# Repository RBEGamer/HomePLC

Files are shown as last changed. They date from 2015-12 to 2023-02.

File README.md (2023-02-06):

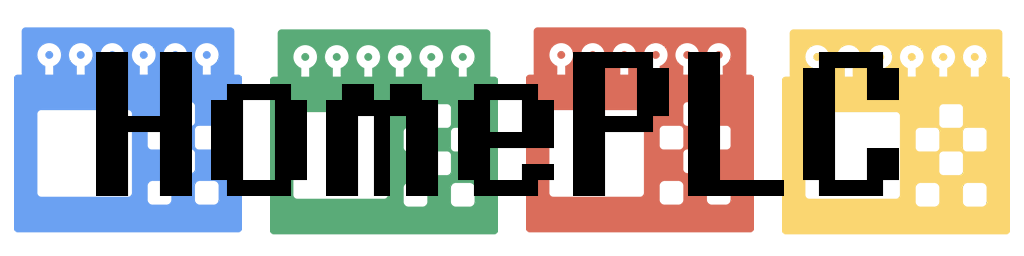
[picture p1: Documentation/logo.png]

HomePLC is a PLC for smarthome purposes, to control your lamps, devices or machines. 
You can use as input several sensors or webservices. For the HomePLC you will need at least the main unit. 
The main unit contains a RaspberryPi witch run the HomePLC-Server software.
As connection to the modules (like relais, sensors,..), it uses a standard USB2RS485 stick.
To connect the Mainunit to the modules it uses a 4 wire standard cable, which contains power and serial data. 
The Serial data bus is RS485@9600 but you can change it to our needs.

# Features:
* RaspberryPi and Arduino based hardware
* PLC oriented programming node based programming language
* Simple Programming Interface
* Arduino Based Hardware Extentions (DMX, Relais, SensorInterfaces, Analog Inputs, GPS, RTC, RS485, PWM-Output,...)
* Webservice integration (OpenWeatherMap,Philips Hue, Netatmo)
* Din Rail Case for integration into exisitng PLC Systems
* Debug webserver at port 5555
* LUA scripting integration to create complex control flows and create your own programming nodes
* Simple Full-Duplex RS485 Protocol to connect further hardware
* Actor and sensor can be combined in one module

# HARDWARE (MAIN UNIT)
* Linux based computer, to mount it at the DIN-Rail i used a RaspberryPi 3
* 5V and 12V switching power supply (search for combined)
* Arduino Micro (for controlling system status: LED, LCD, POWER)
* I2C 16x2 Display for status information
* 3 LEDs for power, error and message signals
* Sub-D9 female connector to connect modules
* 2 USB2Serial converter, if your linux board have no gpio based serial port 
* RS485 transceiver chip [optional isolated]
* DIN-Rail case

# HARDWARE 4-DO (SAMPLE MODULE)
* Din-Rail case
* 2 state leds [optional]
* Arduino micro
* RS485 transceiver chip [optional isolated]
* 2 Sub-D9 female connectors [in/out]
* 4 channel relais board

# SOFTWARE
The software are splitted in two parts :
* HomePLC-Server (runs on your main unit to control your devices, this repo)
* HomePLC-Commander (Design the interaction beween the modules and create the schematic files and upload it to your main unit)

### The HomePLC_Commander software was moved to [HomePLC_Commander](https://github.com/RBEGamer/HomePLC_Commander)

###  SCHEMATIC
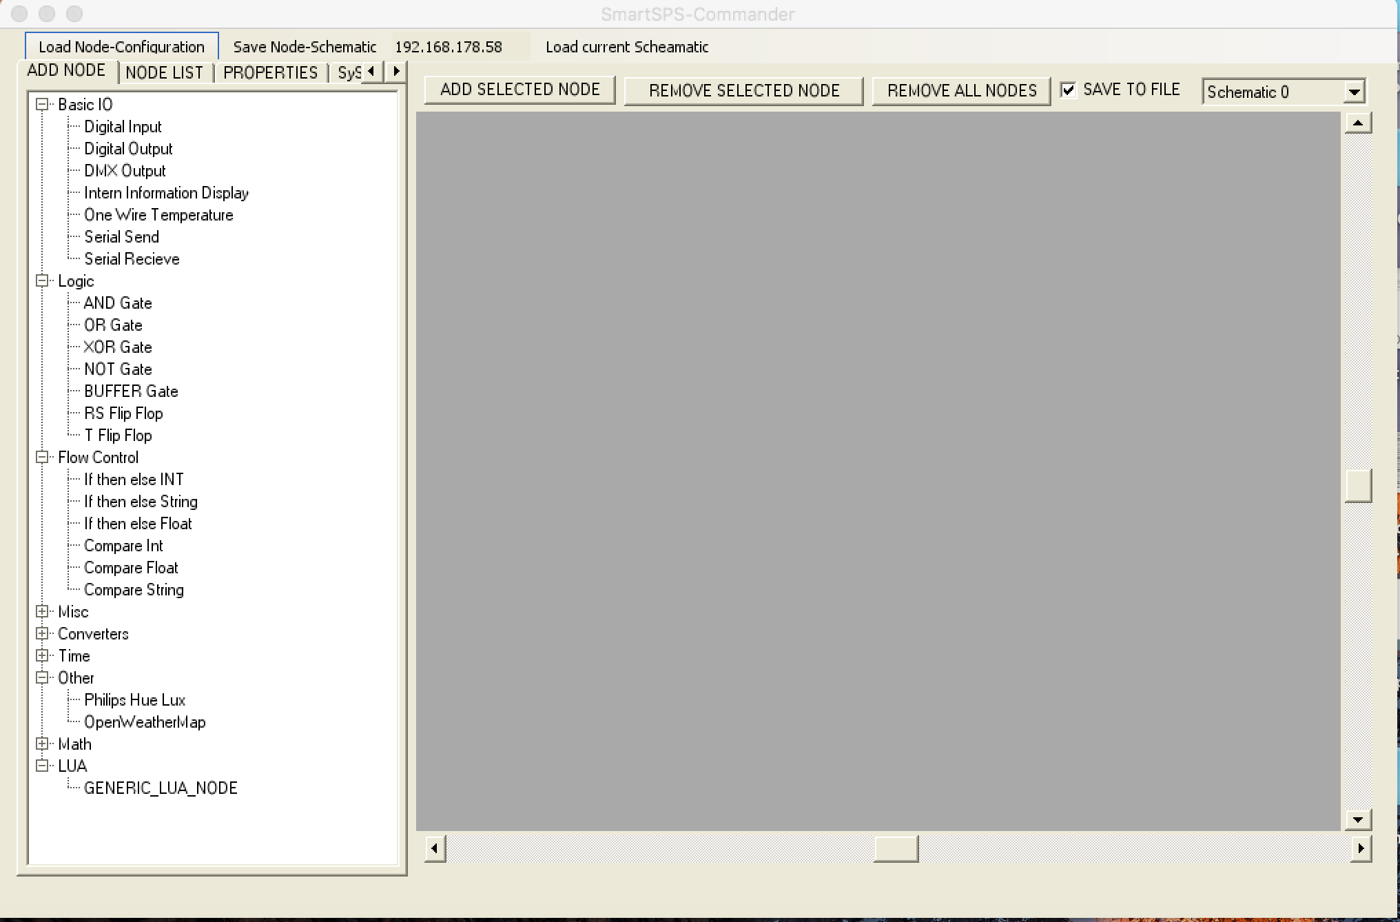
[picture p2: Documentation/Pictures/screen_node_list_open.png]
screen_node_list_open


###  NODE PARAMETER EDITOR
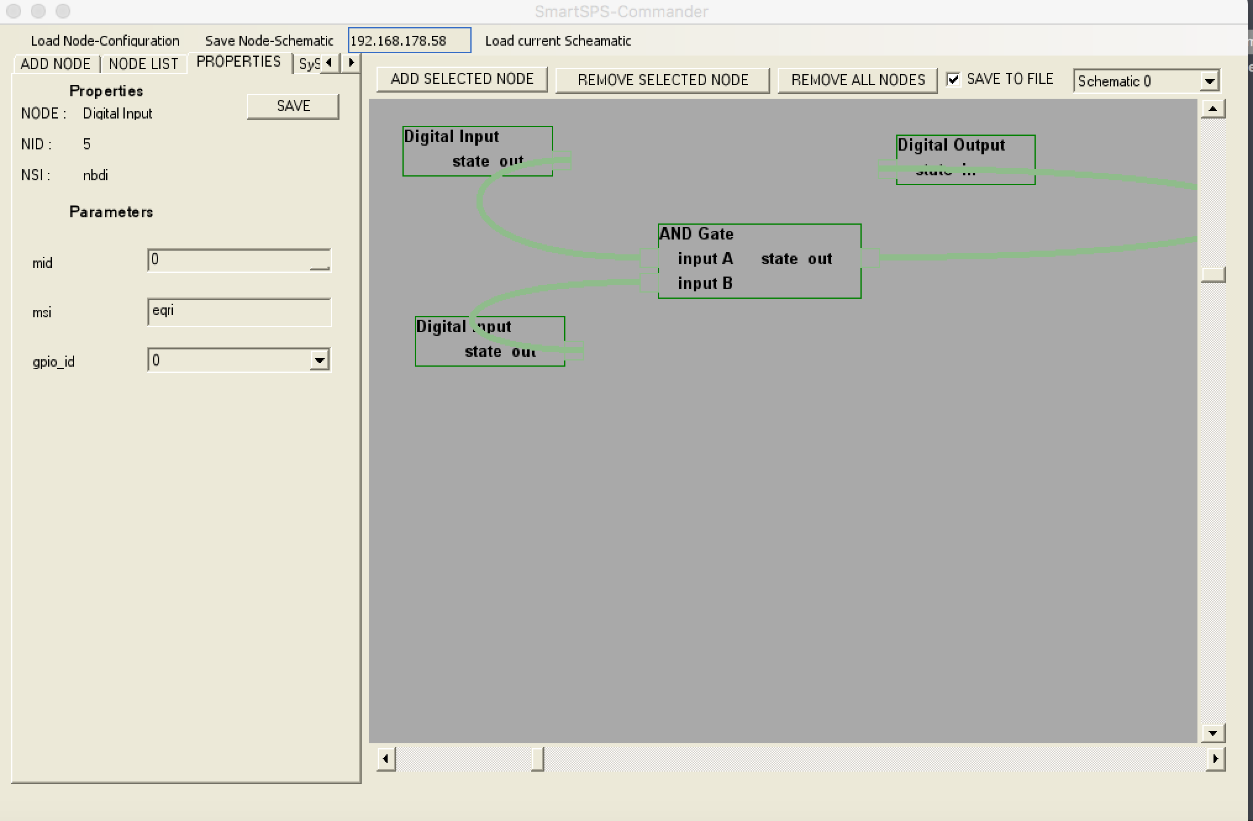
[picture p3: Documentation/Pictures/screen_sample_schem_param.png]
screen_sample_schem_param


The HomePLC schematic is a grafical control language (like FUP) to design the control logic.
You have several nodes like standard logical operations :
* AND, OR, NOT,...
* FLIPFLOS
* MATH
* CONSTANS
* Time/r Nodes
* Compares
* Serial IN/OUT
* TCP/UDP IN/OUT
* DMX send

All other currently implemented nodes are located at:
`./Documentation/Implmented Nodes.csv`

If you have designed a schematic, enter the ip to upload a xml design file to the HomePLC-MainUnit.
The main unit will restart and will start to execute the new schematic. 
You can see the process and errors over the debug interfache.

# LOCATIONS
* A debug build of the HomePLC-Server for the RaspberryPi3 is located at `/Source/BUILDS/BUILD_15_01_2016/`
* The source of the HomePLC-Server to build ith on your own system is located at `./Source/SmartSPS/`
* The HomePLC-Commander source is located at `./Source/SmartPLC_Commander/`
* Sample programs for the HomePLC-Commander are located at `./Documentation/SampleConfig/for_smartsps_commander/`
* Pictures of the MainUnit hardware are located at `./Documentation/Pictures/`

# TODO
* Add MODBUS-TCP
* Add realtime node debugging
* Add cmakelists

# IMAGES
###  BASE MAIN UNIT
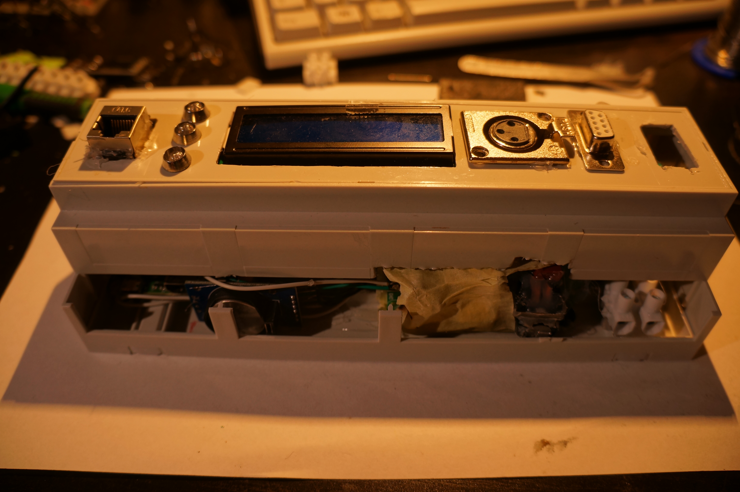
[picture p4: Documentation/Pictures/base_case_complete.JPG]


### TWO EXTENTIONS (left 6 channel relais, right, 12 channel analog input)
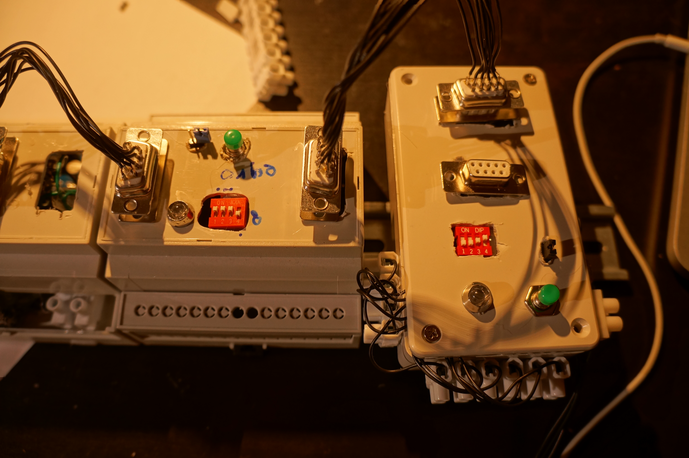
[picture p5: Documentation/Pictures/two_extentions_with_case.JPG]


### OPEN MAIN UNIT
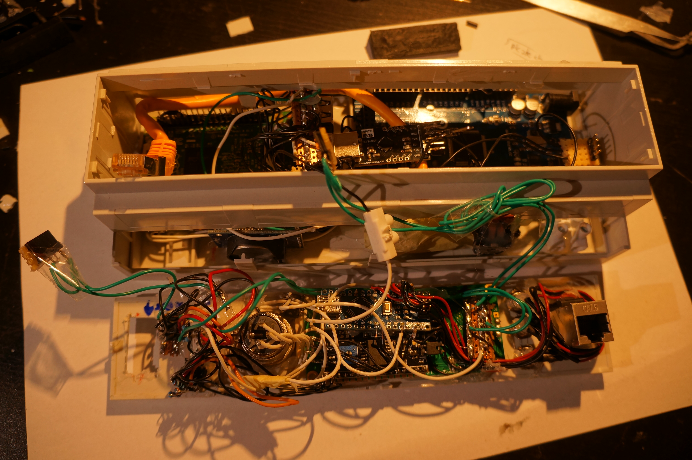
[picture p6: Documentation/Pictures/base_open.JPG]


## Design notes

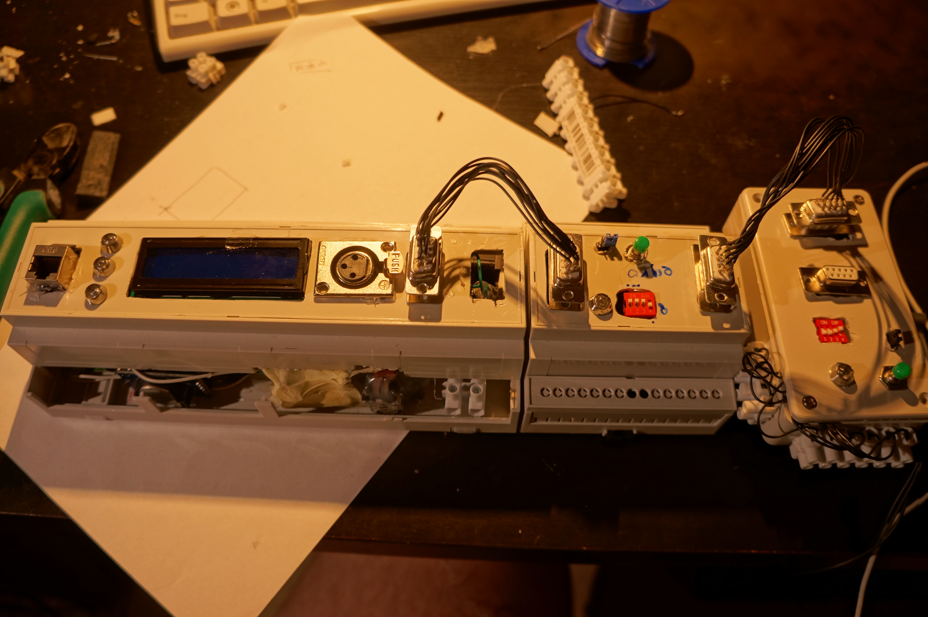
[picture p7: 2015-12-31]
Documentation/Pictures/base_with_two_extentions.JPG

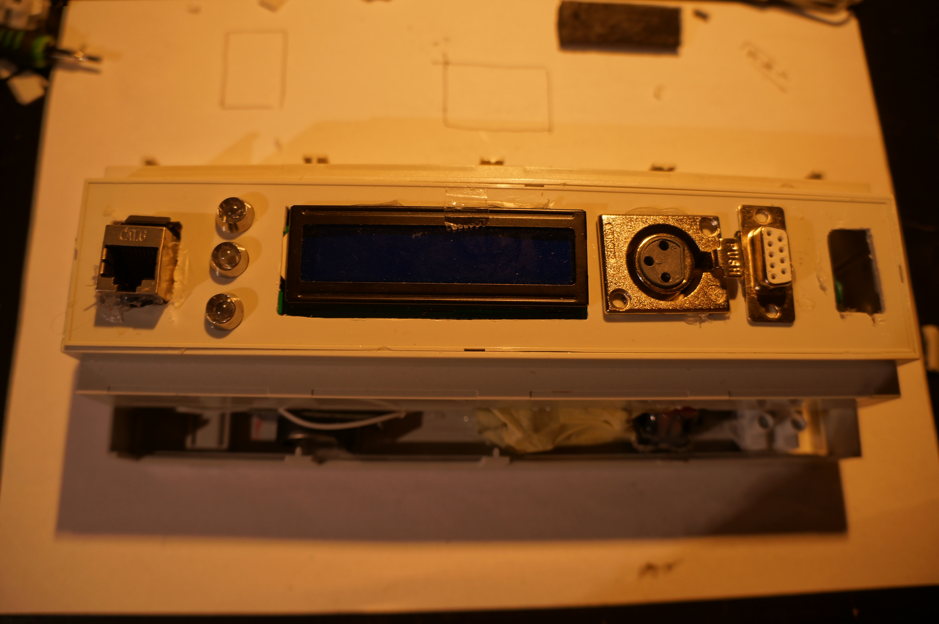
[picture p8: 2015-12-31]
Documentation/Pictures/base_case_complete_top.JPG

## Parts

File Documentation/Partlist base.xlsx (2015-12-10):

Tabelle 1
 | Anzahl | Bez | dist | für ? | € per stück | link
 | 2 | 5v Trafo | ebay |  | 4.95
 | 1 | 16x2 Display i2c | ebay |  | 5
 | 1 | dmx buchse
 | 1 | dpi zero
 | 2 | usb to serial
 | 3 | led + fassung
 | 2 | sub d9 buchse

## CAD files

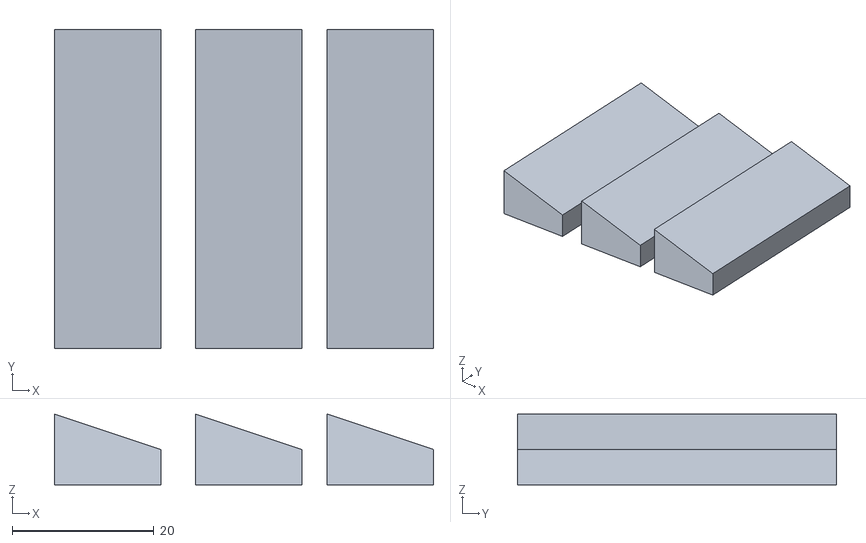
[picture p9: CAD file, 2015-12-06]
Source/3DPrints/KABLE_HOLDER/lüsterklemmenhalter_sketchup.stl
53.5 x 45.0 x 10.0

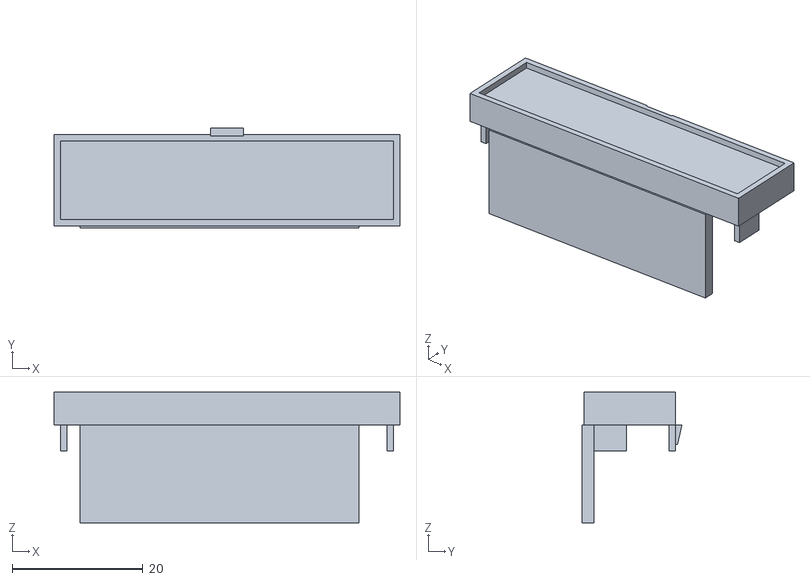
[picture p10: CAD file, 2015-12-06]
Source/3DPrints/VERSCHLUSS/gehäuse_verschluss.stl
53.0 x 15.3 x 20.0

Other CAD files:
Source/3DPrints/KABLE_HOLDER/lüsterklemmenhalter_sketchup.skp
Source/3DPrints/VERSCHLUSS/gehäuse_verschluss_sketchup.skp
Source/3DPrints/VERSCHLUSS/gehäuse_verschluss_sketchup~.skp

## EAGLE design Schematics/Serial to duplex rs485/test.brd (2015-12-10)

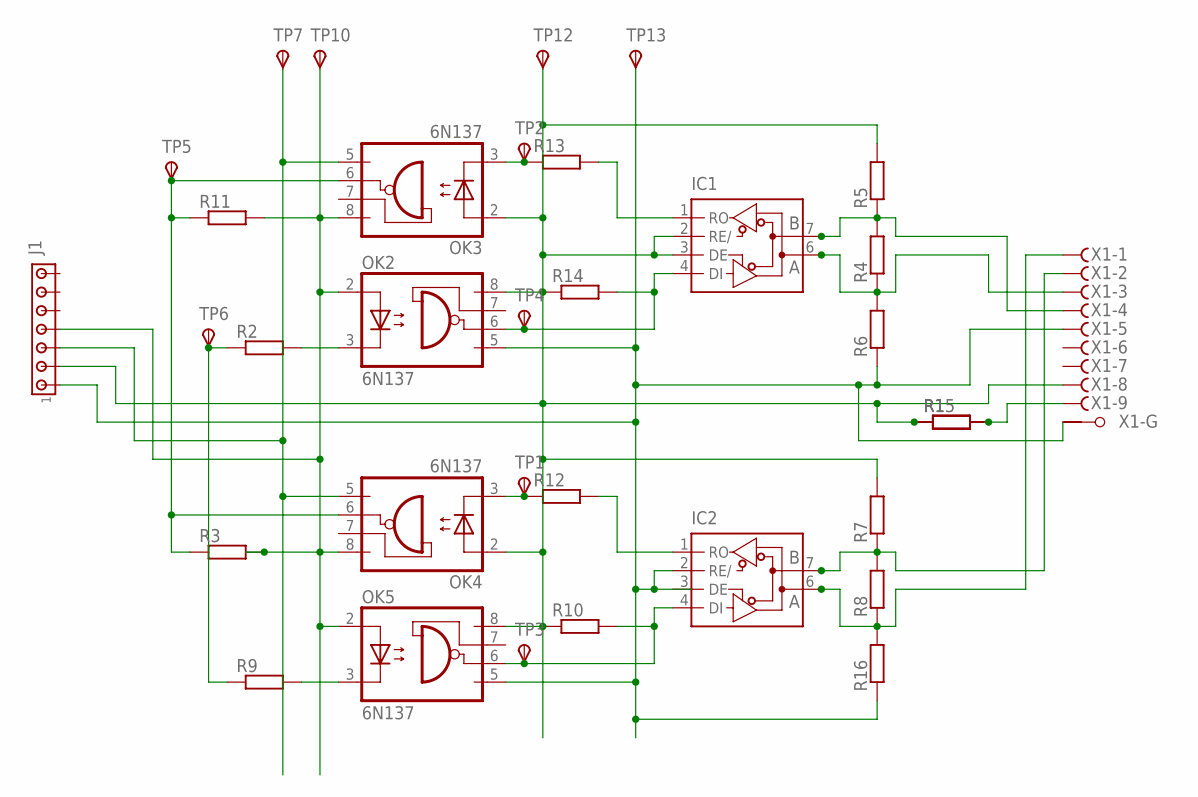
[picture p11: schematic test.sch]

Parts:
IC1, IC2: MAX481CSA; SO08
J1: MTA07-100; 10X07MTA
OK2, OK3, OK4, OK5: 6N137; DIL08
R1, R2, R3, R4, R5, R6, R7, R8, R9, R10, R11, R12, R13, R14, R15, R16: SMK
TP1, TP2, TP3, TP4, TP5, TP6, TP7, TP10, TP12, TP13: TPSB2,54; B2,54
X1: F09HPS; F09HP

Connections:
5VEXT: IC1.2 (RE/), IC1.3 (DE), J1.2, OK2.8 (VCC), OK3.2 (A), OK4.2 (A), OK5.8 (VCC), R1.2, R5.1, R7.1, R10.2, R14.2, R15.2, TP12.TP, X1.8 (F)
GND: IC1.5 (GND), IC2.5 (GND)
unnamed: IC1.7 (B), R4.1, R5.2, X1.4 (F)
unnamed: IC1.6 (A), R4.2, R6.1, X1.3 (F)
unnamed: IC2.7 (B), R7.2, R8.1, X1.2 (F)
unnamed: IC2.6 (A), R8.2, R16.1, X1.1 (F)
unnamed: OK3.3 (C), R13.2, TP2.TP
unnamed: IC1.1 (RO), R13.1
unnamed: OK5.3 (C), R9.1
unnamed: OK4.3 (C), R12.2, TP1.TP
unnamed: J1.3, OK3.5 (GND), OK4.5 (GND), TP7.TP
unnamed: R1.1, R15.1, X1.9 (F)
unnamed: IC2.4 (DI), OK5.6 (VO), R10.1, TP3.TP
unnamed: IC1.4 (DI), OK2.6 (VO), R14.1, TP4.TP
unnamed: OK2.3 (C), R2.1
unnamed: IC2.2 (RE/), J1.1, OK2.5 (GND), OK5.5 (GND), R6.2, R16.2, TP13.TP, X1.5 (F), X1.G1
unnamed: J1.4, OK2.2 (A), OK3.8 (VCC), OK4.8 (VCC), OK5.2 (A), R3.1, R11.1, TP10.TP
unnamed: R2.2, R9.2, TP6.TP
unnamed: OK3.6 (VO), OK4.6 (VO), R3.2, R11.2, TP5.TP
unnamed: IC2.1 (RO), R12.1
VCC: IC1.8 (VCC), IC2.8 (VCC)

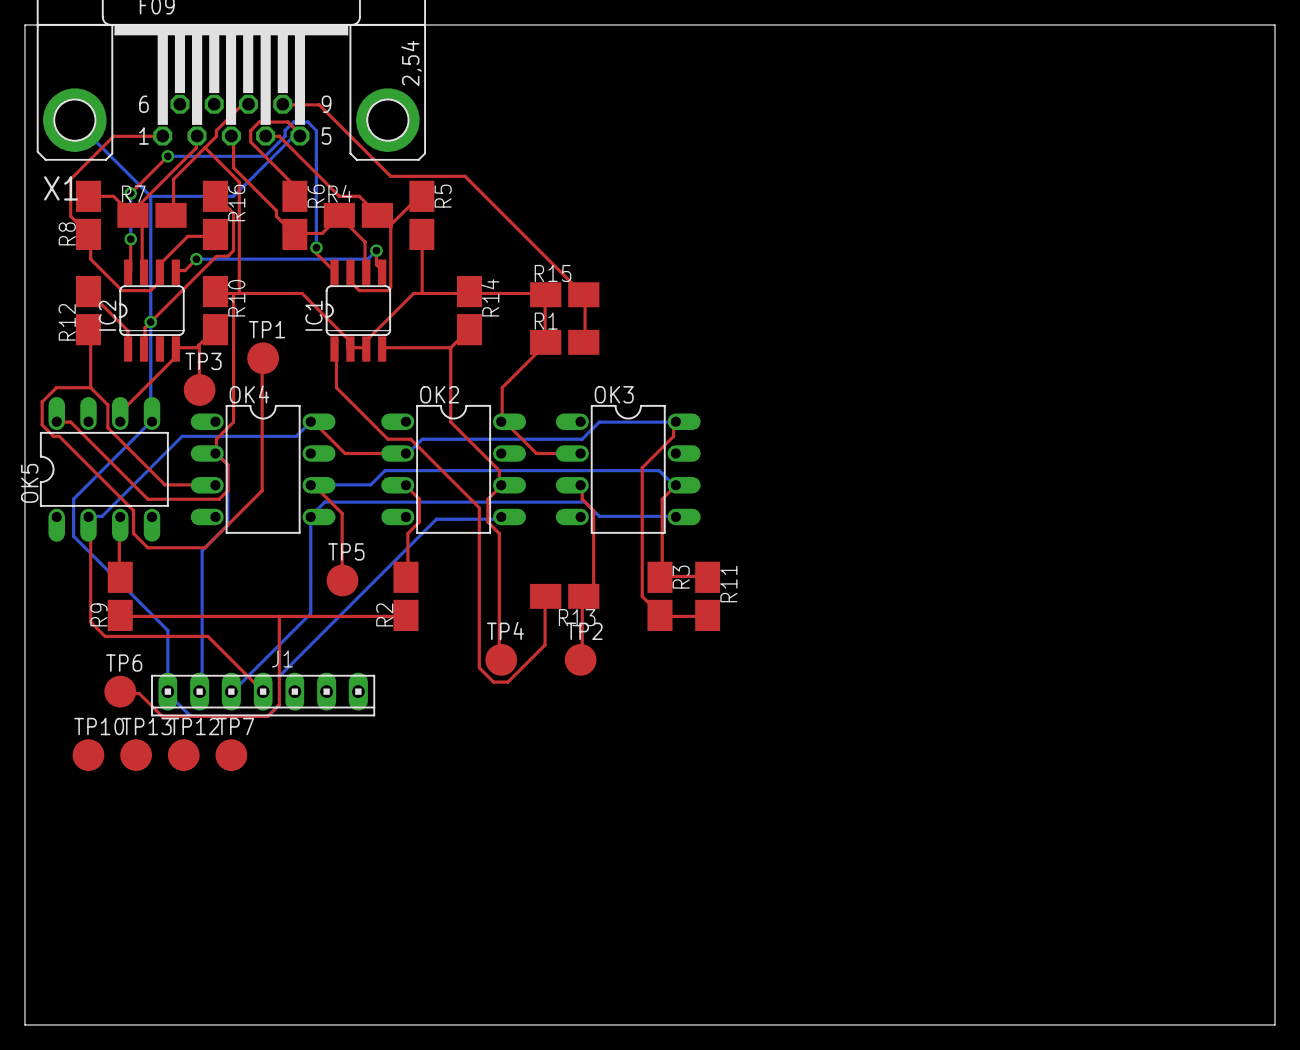
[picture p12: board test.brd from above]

Board: 2 copper layers, 100.0 x 80.0 mm, 34 parts (0 on the bottom side), 21 nets.

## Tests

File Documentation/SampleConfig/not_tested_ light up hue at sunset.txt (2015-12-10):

<?xml version="1.0"?>
<schematic>

<node nid="6" nsi="ctimest" ncon="6:0:7:0%" nparam="%" />
<node nid="7" nsi="tstoint" ncon="7:8:8:0%7:8:14:1%" nparam="%" />
<node nid="8" nsi="strcomp" ncon="8:2:9:0%" nparam="==%" />
<node nid="3" nsi="opwemare" ncon="3:1:2:0%" nparam="25d86d23507280aa2bc0ce79d269ebb8%2925533%sunrise%" />
<node nid="2" nsi="tstoint" ncon="2:8:8:1%" nparam="%" />
<node nid="1" nsi="basetimer" ncon="1:5:3:0%1:5:4:0%1:5:12:0%" nparam="%" />
<node nid="4" nsi="blnot" ncon="4:1:1:1%" nparam="%" />
<node nid="5" nsi="nbcofl" ncon="5:0:1:0%" nparam="50.0%" />

<node nid="9" nsi="blfrs" ncon="9:2:10:0%9:2:11:1%" nparam="" />
<node nid="10" nsi="blbuffer" ncon="" nparam="" />
<node nid="11" nsi="blfrs" ncon="11:2:10:1%11:2:9:1%" nparam="" />

<node nid="12" nsi="opwemare" ncon="12:1:13:0%" nparam="25d86d23507280aa2bc0ce79d269ebb8%2925533%sunset%" />
<node nid="13" nsi="tstoint" ncon="13:8:14:0%" nparam="%" />
<node nid="14" nsi="strcomp" ncon="14:2:11:0%" nparam="==%" />

<node nid="18" nsi="nbcoin" ncon="18:0:15:1%" nparam="20%" />
<node nid="17" nsi="nbcoin" ncon="17:0:15:2%" nparam="255%" />
<node nid="15" nsi="bifte" ncon="15:3:15:0%" nparam="%" />
<node nid="16" nsi="phhlux" ncon="%" nparam="192.168.178.38%9ee891920b34397369b895d195d4a9b%1%" />

</schematic>

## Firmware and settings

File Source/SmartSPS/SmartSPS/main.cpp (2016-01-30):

#if defined(__NO_USE_FF__)
#define __FILE__ ""
#define __LINE__ -1
#endif


#if defined(_LINUX_)
#include <iostream>
#include <ctime> //timer class 
#include <stdio.h>
#include <stdlib.h>
#include<sys/socket.h>
#include<arpa/inet.h> //inet_addr
#include<unistd.h>    //write
#include <fcntl.h>			//Used for UART
#include <termios.h>		//Used for UART
#include <string>
#include <unistd.h>
#include<netinet/in.h>
#include <sys/types.h>
#include <sys/socket.h>
#include <netinet/in.h>
#include <netdb.h>
#include <stdlib.h>
#include <string.h>
#include <arpa/inet.h>
#define closesocket(s) close(s)
#include <math.h>
#include <vector>
#include "pthread.h"
#include <csignal>
#endif




#if defined(_WIN_)
#include <iostream>
#include <windows.h>
#include <string>
#include <vector>
#include <vector>
#include <thread>
#include <ctime> //timer class 
#endif



extern "C" {
#include "lua.h"
#include "lualib.h"
#include "lauxlib.h"
}

#if defined(_MAC_)
#endif

#include "main_node_include.h"





//INIT STATIC VARIABLES
std::deque<std::string> serial_management::recieve_queue = std::deque<std::string>();
std::deque<std::string> serial_management::send_queue = std::deque<std::string>();
int uart0_filestream = -1;
serialib LS;                                                            // Object of the serialib class
int Ret;             //returns the recieved serial chars                                                   // Used for return values
char Buffer[128]; //for the serial recieve
base_node** nodes_buffer;
int end_loop_ticks = 0;
int start_loop_ticks = 0;
float average_delta_time = 0.0f;
float delta_time = 0.0f; //current updatetime in loop
bool break_update_cycle = false; //if false the programm exits
float serial_update_timer = 0.0f;
float serial_update_timer_max = 0.9f; //check for serial updates all
std::string* connection_string;//holds all connection inforamtion
std::stringstream ss;
int node_amount = 0;
bool first_iteration = true;
pthread_mutex_t state_mutex = PTHREAD_MUTEX_INITIALIZER;

enum programm_todo_state
{
	reload, stop, none
};
programm_todo_state current_todo_state;

size_t getTotalSystemMemory()
{
#if defined(_LINUX_)
	long pages = sysconf(_SC_PHYS_PAGES);
	long page_size = sysconf(_SC_PAGE_SIZE);
	return pages * page_size;
#endif
#if defined(_WIN_)
	MEMORYSTATUSEX status;
	status.dwLength = sizeof(status);
	GlobalMemoryStatusEx(&status);
	return status.ullTotalPhys;
#endif
}

uint32_t getTick() {
#if defined(_LINUX_)
	struct timespec ts;
	unsigned theTick = 0U;
	clock_gettime(CLOCK_REALTIME, &ts);
	theTick = ts.tv_nsec / 1000000;
	theTick += ts.tv_sec * 1000;
	return theTick;
#endif
#if defined(_WIN_)
	return getTickCount();
#endif
}

std::string request_schematic() {
std::cout << "STARTIC DOWNLOADING NEWEST SCHEMATIC VERSION" << std::endl;
	char result;
	struct sockaddr_in server;
	struct hostent *host_info;
	in_addr_t addr;
	int sock;
	char buffer[256];
	int count;

	int iResult = 0;
	std::string opm_url = "localhost";
	std::string ret_str = "";
	/* Erzeuge das Socket */
	sock = socket(PF_INET, SOCK_STREAM, 0);
	if (sock < 0) {
		return "";
		exit(1);
	}

	/* Erzeuge die Socketadresse des Servers
	* Sie besteht aus Typ, IP-Adresse und Portnummer */
	memset(&server, 0, sizeof(server));
	addr = inet_addr(opm_url.c_str());
	if (addr != INADDR_NONE) {
		/* argv[1] ist eine numerische IP-Adresse */
		memcpy((char *)&server.sin_addr, &addr, sizeof(addr));
	}
	else {
		/* Wandle den Servernamen in eine IP-Adresse um */
		host_info = gethostbyname(opm_url.c_str());
		if (NULL == host_info) {
			return "";

		}
		memcpy((char *)&server.sin_addr, host_info->h_addr, host_info->h_length);
	}

	server.sin_family = AF_INET;
	server.sin_port = htons(80);

	/* Baue die Verbindung zum Server auf */
	if (connect(sock, (struct sockaddr*)&server, sizeof(server)) < 0) {
		return "";

	}



	std::string ln1 = "GET /smartsps/schematic.xml";
	ln1.append(" HTTP/1.0\r\nHost: ");
	ln1.append(opm_url);
	ln1.append("\r\nAccept: text/html\r\n\r\n");




	char recvbuf1[4096];
	int recvbuflen1 = 4096;
	int rf = 0;


	iResult = send(sock, ln1.c_str(), ln1.size(), 0);

	int end = -1;
	int flen = -1;
	std::string str1 = "";
	int contentSize = 0;
	while (true)
	{
		rf = recv(sock, recvbuf1, recvbuflen1, 0);
		if (end == -1) {
			contentSize += rf;
			str1 += recvbuf1;
			end = str1.find("\r\n\r\n"); //data begin
			if (end != -1)
			{
				end += 4;
				char* start_content_key = strstr(recvbuf1, "Content-Length:") + 15; //cl begin
				char* end_content_key = strstr(start_content_key, "\r\n"); //cl end
				std::string clen;
				clen.append(start_content_key, end_content_key);
				flen = atoi(clen.c_str());
				int s = str1.size();
				int off = rf - (contentSize - end);
				contentSize = rf - off;
				//ret_str += (recvbuf1 + off);
			}
		}
		else {
			int size = std::min(rf, flen - contentSize);
			contentSize += size;
			//ret_str.append(&recvbuf1+flen - size, recvbuf1);
			if (contentSize >= flen) { break; };
		}
	}

	closesocket(sock);


	char* _start_content_key = strstr(recvbuf1, "\r\n\r\n") +4;
	ret_str.append(_start_content_key);
	return ret_str;
	

}

// TESTED XML PARSER
namespace xml_parser {

	//CHECK PASSED---------------------------------------------------------
	//get the versionstring of the start of the xml file
	std::string get_xml_version(const std::string xml_input) {
		std::string final_xml_version_string = "";
		const char *xml_version_string_begin = strstr(xml_input.c_str(), "<?xml ");
		if (xml_version_string_begin != 0) { //if
			xml_version_string_begin += 6; //remove the "<?xml "
			const char *xml_version_string_end = strstr(xml_version_string_begin, "?>");
			if (xml_version_string_end != 0) {
				std::string xml_version_string_content = "";
				xml_version_string_content.append(xml_version_string_begin, xml_version_string_end); //result: version='1.0'
				const char *xml_version_content_verion_start = strstr(xml_version_string_content.c_str(), "version=");
				if (xml_version_content_verion_start != 0) {
					xml_version_content_verion_start += 9; //remove version='
					const char *xml_content_version_end = strstr(xml_version_content_verion_start, "\"");
					if (xml_content_version_end != 0) {
						final_xml_version_string.append(xml_version_content_verion_start, xml_content_version_end);
					}
				}
			}
		}
		return final_xml_version_string;
	}
	//CHECK PASSED---------------------------------------------------------

	//CHECK PASSED---------------------------------------------------------
	//gets the content of the root node a root node is defined by <name></name>
	std::string get_xml_root_node_content(const std::string xml_input, const std::string node_name) {
		std::string schematic_content = "";
		const std::string nnbegin = "<" + node_name + ">";
		const std::string nnend = "</" + node_name + ">";
		const char* schematic_content_start = strstr(xml_input.c_str(), nnbegin.c_str());
		if (schematic_content_start != 0) {
			schematic_content_start += nnbegin.size(); //remove the <schematic>
			const char* schematic_content_end = strstr(schematic_content_start, nnend.c_str());
			if (schematic_content_end != 0) {
				schematic_content.append(schematic_content_start, schematic_content_end);
			}
		}
		return schematic_content;
	}
	//CHECK PASSED---------------------------------------------------------

	//CHECK PASSED---------------------------------------------------------
	//returns the amount of elements
	int get_element_count(const std::string xml_input, const std::string node_name) {
		std::string element_name = "<" + node_name; //create the complete  element start name without space (" ")!!
													//count the  "<nodename " to alloc the result string array
		const char* xml_element_start_count = strstr(xml_input.c_str(), element_name.c_str());
		int array_size = 0;
		while (true) {
			xml_element_start_count = strstr(xml_element_start_count, element_name.c_str());
			if (xml_element_start_count != 0) {
				xml_element_start_count += element_name.size();
				array_size++;
			}
			else {
				break;
			}
		}
		return array_size;
	}
	//CHECK PASSED---------------------------------------------------------

	//CHECK PASSED---------------------------------------------------------
	//gets the content of all nodes with the spcified name you can process the result (xmlkvp with the callback function
	void get_element_content(const std::string xml_input, const std::string node_name, void(*callback_func)(std::string*, int)) {
		std::string element_name = "<" + node_name; //create the complete  element start name without space (" ")!!
													//count the  "<nodename " to alloc the result string array
		const char* xml_element_start_count = strstr(xml_input.c_str(), element_name.c_str());
		int array_size = 0;
		while (true) {
			xml_element_start_count = strstr(xml_element_start_count, element_name.c_str());
			if (xml_element_start_count != 0) {
				xml_element_start_count += element_name.size();
				array_size++;
			}
			else {
				break;
			}
		}

		if (array_size > 0) {
			//node_counter = array_size;
			//	const int f_array_size = const_cast<const int&>(array_size);
			std::string* xml_elements_content = 0;
			xml_elements_content = new std::string[array_size];
			int array_pop_counter = 0; //counter for correct array asign
			if (xml_input.size() > 0) {
				const char* xml_element_start = strstr(xml_input.c_str(), element_name.c_str());
				while (true) {
					xml_element_start = strstr(xml_element_start, element_name.c_str());
					if (xml_element_start != 0) {
						xml_element_start += element_name.size(); //remove the <node
						const char* xml_element_end = strstr(xml_element_start, "/>");
						if (xml_element_end != 0) {
							xml_elements_content[array_pop_counter] = "";
							std::string xml_element_content = "";
							xml_element_content.append(xml_element_start, xml_element_end);
							xml_elements_content[array_pop_counter] = xml_element_content;
							callback_func(xml_elements_content, array_pop_counter);
							xml_element_start = xml_element_end + 2;
							array_pop_counter++;
						}
						else { break; }
					}
					else { break; }
				}
			}
			delete[]xml_elements_content; //delete array
		}//ende if arraysize > 0
	}
	//CHECK PASSED---------------------------------------------------------

	//CHECK PASSED---------------------------------------------------------
	//basic string replace function
	void replaceAll(std::string& str, const std::string& from, const std::string& to) {
		if (from.empty())
			return;
		size_t start_pos = 0;
		while ((start_pos = str.find(from, start_pos)) != std::string::npos) {
			str.replace(start_pos, from.length(), to);
			start_pos += to.length(); // In case 'to' contains 'from', like replacing 'x' with 'yx'
		}
	}
	//CHECK PASSED---------------------------------------------------------

	//CHECK PASSED---------------------------------------------------------
	//prepare the xml input : replace some charakters,
	void prepare_xml_input(std::string& xml_input) {
		//replaceAll(xml_input, std::string(char(39), sizeof(char)), std::string(char(34), sizeof(char))); //replace " with '
		replaceAll(xml_input, "", "\r\n");
		replaceAll(xml_input, "", "\n");
		replaceAll(xml_input, "\" = \"", "\"=\"");
		replaceAll(xml_input, " = ", "=");
		replaceAll(xml_input, "> <", "><");
	}
	//in this function you can process your xml results you can define an other function with the functionpointer-parameter in the get_element_content or get_element attribute
	//CHECK PASSED---------------------------------------------------------

	//CHECK PASSED---------------------------------------------------------
	//get the key value pairs of the result from the get_element_content_function
	std::string get_element_attributes(const std::string xml_input, const std::string element_name) {
		const char* xml_element_key_start = strstr(xml_input.c_str(), element_name.c_str());
		std::string result_string = "";
		if (xml_element_key_start != 0)
		{
			xml_element_key_start += element_name.size() + 2; //to remove the emelement name + the ="
			if (xml_element_key_start != 0)
			{
				const char* xml_element_key_end = strstr(xml_element_key_start, "\"");
				if (xml_element_key_end != 0)
				{
					result_string.append(xml_element_key_start, xml_element_key_end);
					return result_string;
				}
				else {
					return "";
				}
			}
			else
			{
				return "";
			}
		}
		else {
			return "";
		}
		return "";
	}
	//CHECK PASSED---------------------------------------------------------

}
// global variable to share data
namespace debug_server
{
	std::vector<std::string> debug_data_storage;
	pthread_mutex_t t1_mutex = PTHREAD_MUTEX_INITIALIZER;
	pthread_mutex_t log_level_mutex = PTHREAD_MUTEX_INITIALIZER;
	int sockfd, portno, clilen;
	pthread_t t1;
	std::string final_html;
	enum debug_level_enum
	{
		ERROR, WARNING, INFO
	};
	debug_level_enum current_debug_level;
	// This function will run concurrently.

	void add_debug_data(int debug_level,std::string file,int line, std::string key, std::string value) {


		switch (current_debug_level)
		{
		case ERROR:
			if (debug_level == 0 || debug_level == 1) { return; }
			break;
		case WARNING:
			if (debug_level == 0) { return; }
			break;
		case INFO:
			break;
		default:
			break;
		}
		final_html = "";

		final_html.append("<table border=\"1\"><tr>");

		struct timeval tv;
		gettimeofday(&tv, NULL);
		time_t tt = tv.tv_sec;
		struct tm * ptm = localtime(&tt);
		char buf[30];
		strftime(buf, 30, "%m:%d:%Y-%H:%M:%S", ptm);
		final_html.append("<td width=\"100px\">");
		final_html.append(buf);
		final_html.append("</td>");


		//ADD LEVLE CHECK

		//ADD MESSAGE TYPE

		if (debug_level == 0) {
			final_html.append("<td width=\"100px\" ><b> <p style=\"color : green\">INFO</p></b></td>");
		}
		else 	if (debug_level == 2) {
			final_html.append("<td width=\"100px\" ><b><p style=\"color : red\">ERROR</p></b></td>");
		}
		else 	if (debug_level == 1) {
			final_html.append("<td width=\"100px\" ><b><p style=\"color : yellow\">WARNING</p></b></td>");
		}
		else if (debug_level == -1) {
			final_html.append("<td width=\"100px\" ><b> <p style=\"color : green\">SYS-INFO</p></b></td>");
		}

		final_html.append("<td  width=\"150px\" >");
		final_html.append(file);
		final_html.append("</td><td  width=\"150px\" >");
		final_html.append(NumberToString(line));
		final_html.append("</td><td  width=\"150px\" >");
		final_html.append(key);
		final_html.append("</td><td  width=\"400px\" >");
		final_html.append(value);
		final_html.append("</td></tr></table>");



		//LOCK 


		volatile bool got_lock = false;
		while (!got_lock) {
			if (pthread_mutex_trylock(&t1_mutex) == 0) {
				got_lock = true;
				debug_data_storage.insert(debug_data_storage.end() - 1, final_html);
				pthread_mutex_unlock(&t1_mutex);
			}
		}





		//DELOCK
	}



	void doprocessing(int sock) {
		int n;
		char buffer[256];
		bzero(buffer, 256);


		volatile bool found = false;
		int end = -1;
		std::string com_buffer = "";
		std::string requested_data = "";
		while (!found)
		{
			n = read(sock, buffer, 255);

			if (n < 0) {
				perror("ERROR reading from socket");
				exit(1);
			}


			if (n > 0) {
				com_buffer += buffer;
				end = com_buffer.find("\r\n\r\n");
				if (end != -1) {
					const char* start = com_buffer.c_str();
					start = strstr(start, "GET ");
					if (start != 0)
					{
						start += 4;
						const char* end = strstr(start, " HTTP/");
						if (end != 0) {
							requested_data.append(start, end);
							found = true;
						}
					}
				}
			}
		}




		std::cout << requested_data << std::endl;


		//SEND DEBUG HEADERS
		if (requested_data == "/debug" || requested_data == "/") {
			int lsize = 0;
			std::string end_msg = "<br>Please see :<br> <a href = '/debug'>DEBUG LOG</a><br><a href = '/shutdown'>SHUTDOWN</a><br><a href = '/reload'>RELOAD SCHEMATIC</ a><br><a href = '/level=info'>Set Debug-Level to INFO</ a><br><a href = '/level=warning'>Set Debug-Level to WARNING</ a><br><a href = '/level=error'>Set Debug-Level to ERROR</ a></body></html>";
			for (size_t i = 0; i < debug_data_storage.size(); i++)
			{
				lsize += debug_data_storage.at(i).size();
			}
			lsize += end_msg.size();
			std::string http_header = "";
			http_header.append("HTTP/1.1 200 OK\r\n");
			http_header.append("Host: 192.168.178.58\r\n");
			http_header.append("Server: Apache/1.1.1\r\n");
			http_header.append("Content-Type: text/html;charset=UTF-8\r\n");
			http_header.append("Connection: clos\r\n");
			http_header.append("Content-Lenght: ");
			http_header.append(NumberToString(lsize));
			http_header.append("\r\n");
			http_header.append("\r\n");
			for (size_t i = 0; i < debug_data_storage.size(); i++)
			{
				http_header.append(debug_data_storage.at(i));
			}
			http_header.append(end_msg);

			write(sock, http_header.c_str(), http_header.size());
			// std::cout << http_header << std::endl;
		}
		else if (requested_data == "/reload") {

			volatile bool got_lock = false;
			while (!got_lock) {
				if (pthread_mutex_trylock(&state_mutex) == 0) {
					got_lock = true;
					current_todo_state = reload;
					pthread_mutex_unlock(&state_mutex);
				}
			}
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
int main(int argc, char *argv[])
{
	//START MAINLOOP
	signal(SIGINT, signalHandler);





	debug_server::start_debug_server(debug_server::INFO);



//INIT SERIAL DEVICE

	Ret = LS.Open("/dev/ttyUSB0", 9600);                                     
	if (Ret != 1) {                                                          
	  
		debug_server::add_debug_data(2, __FILE__, __LINE__, "_SERIAL_", "Error while opening port. Permission problem ?");

		return Ret;                                                       
	}
	std::cout << "NODESERVER V1.2 STARTING THE SERIAL INTERFACE IS: /dev/ttyUSB0" << std::endl;
//	serial_management::add_to_send_queue("0_bnid_0_SmartSPS 1.2\n");
	#if defined(DEBUG)
	//serial_management::add_to_send_queue("0_bnid_1_DEBUG-BUILD\n");
	#endif
	debug_server::add_debug_data(0,__FILE__,__LINE__, "_SYSTEM_", "Serial-Interface : <b>/dev/tty/USB0 at b9600</b>");



	current_todo_state = reload;
	


enter:

	main_loop();

	if (current_todo_state == reload) {

		current_todo_state = none;
		reload_schematic();
		goto enter;
	}
	

	//----- CLOSE THE UART -----
	delete[] nodes_buffer;
	LS.Close();
	debug_server::add_debug_data(0,__FILE__, __LINE__, "_SERIAL_", "Close Serial Connections");
	debug_server::write_log_to_file();
	debug_server::stop_debug_server();
	
	std::cout << "EXIT NODESERVER WITH EXITCODE 0" << std::endl;

	return 0;
}

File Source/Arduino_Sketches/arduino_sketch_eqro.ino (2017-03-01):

/*
  Blink
  Turns on an LED on for one second, then off for one second, repeatedly.

  Most Arduinos have an on-board LED you can control. On the Uno and
  Leonardo, it is attached to digital pin 13. If you're unsure what
  pin the on-board LED is connected to on your Arduino model, check
  the documentation at http://www.arduino.cc

  This example code is in the public domain.

  modified 8 May 2014
  by Scott Fitzgerald
 */
String readString;
int modul_id;
// the setup function runs once when you press reset or power the board
void setup() {
  pinMode(3, OUTPUT); //-> TRANSMIT ENDABLE
  digitalWrite(3, LOW);

  
   digitalWrite(A4, LOW);
Serial.begin(9600);
  // initialize digital pin 13 as an output.
  pinMode(A0, OUTPUT);
  pinMode(A1, OUTPUT);
  pinMode(A2, OUTPUT);
  pinMode(A3, OUTPUT);
  //set all realis to off
digitalWrite(A0, HIGH);
digitalWrite(A1, HIGH);
digitalWrite(A2, HIGH);
digitalWrite(A3, HIGH);


pinMode(A4, OUTPUT);

pinMode(12, INPUT);           // set pin to input
digitalWrite(12, HIGH);       // turn on pullup resistors
pinMode(11, INPUT);           // set pin to input
digitalWrite(11, HIGH);       // turn on pullup resistors
pinMode(10, INPUT);           // set pin to input
digitalWrite(10, HIGH);       // turn on pullup resistors
pinMode(9, INPUT);           // set pin to input
digitalWrite(9, HIGH);       // turn on pullup resistors


  modul_id = -1;
if(digitalRead(9) == 1){modul_id +=1;}
if(digitalRead(10) == 1){modul_id +=2;}
if(digitalRead(11) == 1){modul_id +=4;}
if(digitalRead(12) == 1){modul_id +=8;}


digitalWrite(3, HIGH);
Serial.println("register_eqro_" + String(modul_id));

 digitalWrite(A4, HIGH);
 delay(10);
       Serial.flush();
      digitalWrite(3, LOW);
}

// the loop function runs over and over again forever
void loop() {
if(modul_id > 0){
  

   while (Serial.available()) {
    delay(3);  //delay to allow buffer to fill 
    if (Serial.available() >0) {
      char c = Serial.read();  //gets one byte from serial buffer
      readString += c; //makes the string readString
    } 
  }

  if (readString.length() >0) {
      //Serial.println(readString); //see what was received

if(getValue(readString, '_', 0).toInt() == modul_id){
  if(getValue(readString, '_', 1) == "eqro"){
    digitalWrite(A4, LOW);
    if(getValue(readString, '_', 2) == "set"){
       int port = getValue(readString, '_', 4).toInt();
       digitalWrite(3, HIGH);
       delay(10);
      if(getValue(readString, '_', 3) == "h"){   
       if(port == 0){digitalWrite(A0, LOW);}
       if(port == 1){digitalWrite(A1, LOW);}
       if(port == 2){digitalWrite(A2, LOW);}
       if(port == 3){digitalWrite(A3, LOW);}
      }else if(getValue(readString, '_', 3) == "l"){
       if(port == 0){digitalWrite(A0, HIGH);}
       if(port == 1){digitalWrite(A1, HIGH);}
       if(port == 2){digitalWrite(A2, HIGH);}
       if(port == 3){digitalWrite(A3, HIGH);}
      }
      Serial.flush();
      digitalWrite(3, LOW);
   
      }
      
    }
    digitalWrite(A4, HIGH);
  }
    readString="";
  } 
 }
}





String getValue(String data, char separator, int index)
{
  int found = 0;
  int strIndex[] = {
    0, -1  };
  int maxIndex = data.length()-1;
  for(int i=0; i<=maxIndex && found<=index; i++){
    if(data.charAt(i)==separator || i==maxIndex){
      found++;
      strIndex[0] = strIndex[1]+1;
      strIndex[1] = (i == maxIndex) ? i+1 : i;
    }
  }
  return found>index ? data.substring(strIndex[0], strIndex[1]) : "";
}

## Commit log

2015-12-06 added some project files
    [TEXTCONFIG.txt]
2015-12-06 added 3d print files
    [gehäuse_verschluss.stl, gehäuse_verschluss_sketchup.skp, gehäuse_verschluss_sketchup~.skp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]
2015-12-08 timer fix (not tested) int comp fix
2015-12-08 hue blinking with timer
2015-12-08 added implemented nodes list
    [Implmented Nodes.xlsx]
2015-12-09 added socket downloading for schematic at startup
    downloads the latest schematic on startup from the :
    localhost:80/test.html
    [Implmented Nodes.xlsx]
2015-12-09 added serial to s485 schematics
    [test.brd, test.sch]
2015-12-09 added partlist for base
    [Partlist base.xlsx]
2015-12-09 added string operations
    [Implmented Nodes.xlsx]
2015-12-10 node parsing bugfix
    [Implmented Nodes.xlsx]
2015-12-10 added samples
2015-12-10 added som colors to excel list
    [Implmented Nodes.xlsx]
2015-12-13 edited sample config
2015-12-14 added thread test
2015-12-14 on the fly reload test but server thread not still working
2015-12-16 updated node list
    [Implmented Nodes.xlsx]
2015-12-16 remove bug in xls
    [Implmented Nodes.xlsx]
2015-12-17 added use timer constructor
2015-12-17 nbdi use timer = false
2015-12-25 added one wire sketch
2015-12-25 added power led state to arduino sketches
2015-12-26 added implemented nodes csv
    [Implmented Nodes.csv, Implmented Nodes.xlsx]
2015-12-26 addede new csv and create dyn panel params loading (begin, test)
    [Implmented Nodes.csv]
2015-12-26 added extention name collum to csv
    [Implmented Nodes.csv]
2015-12-26 csv openwathermap bugfix
    [Implmented Nodes.csv]
2015-12-26 added paramerter load funcktion
    [Implmented Nodes.csv]
2015-12-31 added drawing timer
2016-01-01 added gdi drawing prototype
2016-01-01 added fix to connect twiche the same connectors
2016-01-03 save schematic as file
2016-01-06 added protocol xlsx file
    [Extention Protocoll.xlsx]
2016-01-11 multi schematic save
2016-01-12 big mistake fix: call stack ._.
    [Implmented Nodes.csv]
2016-01-15 added temperture node
    [Implmented Nodes.csv]
2016-01-16 more debug stuff
    +added temp schematic
    +bugfix in eowt
    [main.cpp]
2016-01-16 vorbereitung für serial nodes
    [Implmented Nodes.csv]
2016-01-16 added experimental nbss
    [Implmented Nodes.csv]
2016-01-16 added vs filter
2016-01-21 added more infos to xml export
    [Implmented Nodes.csv]
2016-01-21 fix xml export
    [Implmented Nodes.csv]
